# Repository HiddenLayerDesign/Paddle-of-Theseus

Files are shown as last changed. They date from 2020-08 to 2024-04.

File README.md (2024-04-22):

# Paddle-of-Theseus
This Repository holds the design work for Hidden Layer Design's "Paddle of Theseus" project.

Please take a look at [the Wiki](https://github.com/ChaseStewart/Paddle-of-Theseus/wiki) for in-depth information.

## Author
[Chase E Stewart](https://chasestewart.co) for [Hidden Layer Design](https://hiddenlayerdesign.com)

## Repository Contents
* **/Software/PadleFirmware** - Software Arduino project to program the Teensy 4.0. This Teensy is the main microcontroller for this project, and uses input sensor data to output MIDI commands to an external controller.
* **/Software/ClientApp** - Software [FBS](https://build-system.fman.io/)-based [PyQt](https://riverbankcomputing.com/software/pyqt/) project that builds a GUI application to allow users to configure the Paddle's saved settings in EEPROM.
* **/Software/StubPaddle** - Software Python program for ClientApp development to simulate a USB connection to the paddle. Requires a virtual COM port program on Windows to run.
* **/Hardware/Fritzing**   - DEPRECATED Fritzing file for project Hardware _NOTE: HW Diagram uses a Teensy3.1 but I have verified proper function on Teensy4.0 and TeensyLC_
* **/Hardware/Diagrams**   - DEPRECATED HW diagrams generated from the Fritzing file; currently these include a schematic, PCB image, and breadboard diagram
* **/Hardware/Components** - This contains the bill-of-materials for the relevant *electronics only* for this product. 

## Features
This project will create a bass-guitar-like skeumorphic MIDI instrument out of a standard rowing paddle (or arbitrary instrument body) and sensors. The Teensy microcontroller will take in sensor values and provide MIDI output to an external Audio DAW (In our case, we use Ableton Live and sometimes https://midi.city).

## Implementation Requirements
Implementing this project will require some knowledge of electronics, prototyping, and physical fabrication.

### Software Requirements
- [Arduino IDE](https://www.arduino.cc/en/Main/Software)
- [Arduino Teensyduino add-on](https://www.pjrc.com/teensy/td_download.html)
- [Arduino Teensy Loader](https://www.pjrc.com/teensy/loader.html)

### Hardware
The following is required to build this project.
- 1x [Teensy 4.0](https://www.pjrc.com/teensy-4-0/)
- 1x USB Micro cable
- 1x [Ultrasonic Rangefinder](https://www.adafruit.com/product/4019) or equivalent
- 1x [SparkFun Triple Axis Accelerometer Breakout](https://www.sparkfun.com/products/12756) or equivalent
- 1x [RGB Common-Anode Illuminated Rotary Encoder](https://www.sparkfun.com/products/15141)
- 1x [Clear Plastic Rotary Encoder Knob](https://www.sparkfun.com/products/10597)
- 1x [Illuminated Rotary Encoder Breakout Board](https://www.sparkfun.com/products/11722)
- 1x [USB Panel Mount Extension Cable](https://www.adafruit.com/product/3258)
- 1x [Custom CoreModule PCB](#)
- 1x [Custom FretBoard PCB](#)
- 1x [Custom StrumBoard PCB](#)
- Audio Software that supports MIDI (I use Ableton Live 8)

### Assembly
Assemble the Sensors and Teensy according to the schematic and breadboard diagrams in */Hardware/Diagrams*, paying special attention to the labeled inputs.

## Getting Started
- Download All Software Requirements above
  - Install Arduino IDE
  - Install Teensy Loader
  - Install Teensyduino SW libraries
- Clone this Repository
- Open `/Software/Main/main.ino` in Arduino 
- Configure Arduino Settings
  - Set `Tools>Board="Teensy 4.0"` to match the board you are using
  - Set `Tools>USB Type="Serial + MIDI"`
- Compile this project with `"Verify"`, then Flash with `Upload`
  - If needed, press the physical button on the Teensy to enable the bootloader. Ensure Serial connections are closed before hitting `Upload`

## Links
- Personal Website: https://chasestewart.co/
- Hidden Layer Design Website: https://HiddenLayerDesign.com
- Repository: https://github.com/ChaseStewart/Paddle-of-Theseus/

## License
<br />This work is licensed under a <a rel="license" href="http://creativecommons.org/licenses/by-sa/4.0/">Creative Commons Attribution-ShareAlike 4.0 International License</a>.

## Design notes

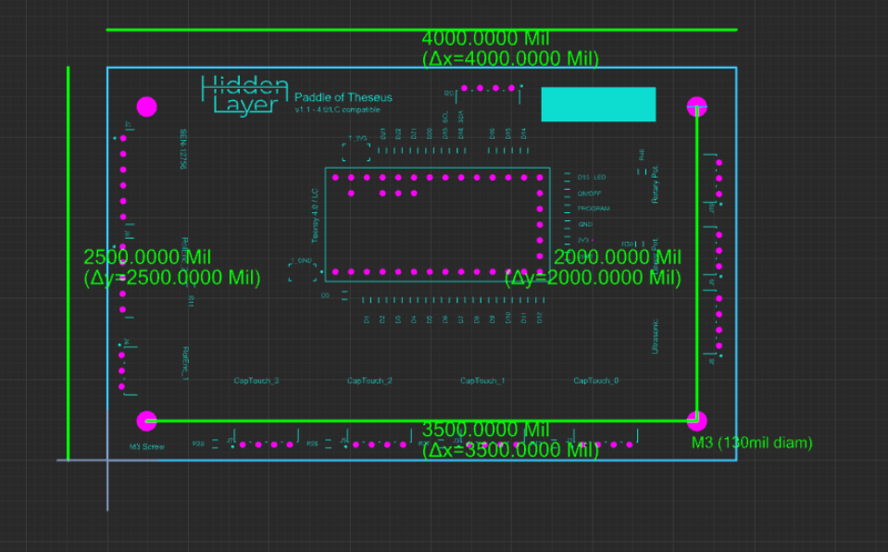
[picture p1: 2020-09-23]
Hardware/Diagrams/PCB Dimensions.PNG

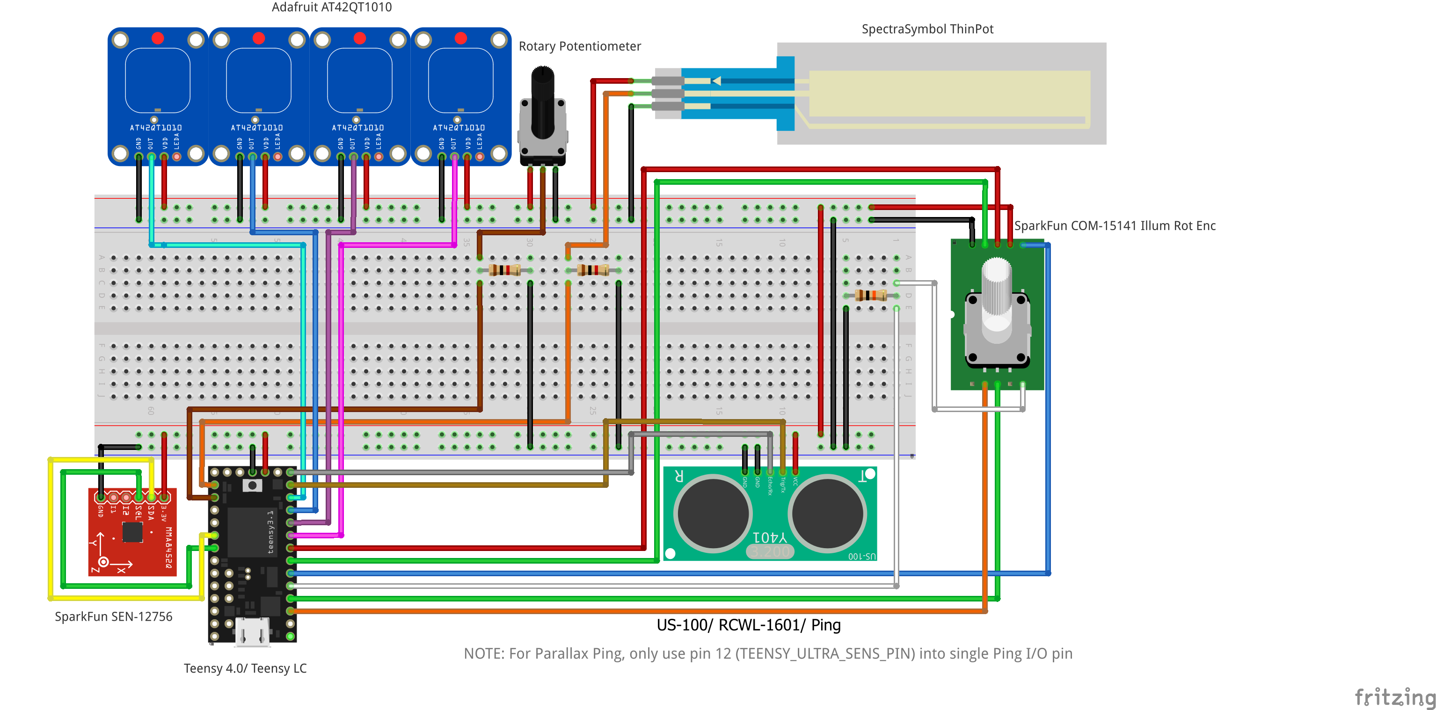
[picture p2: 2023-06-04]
Hardware/Diagrams/Paddle_of_Theseus_bb.png

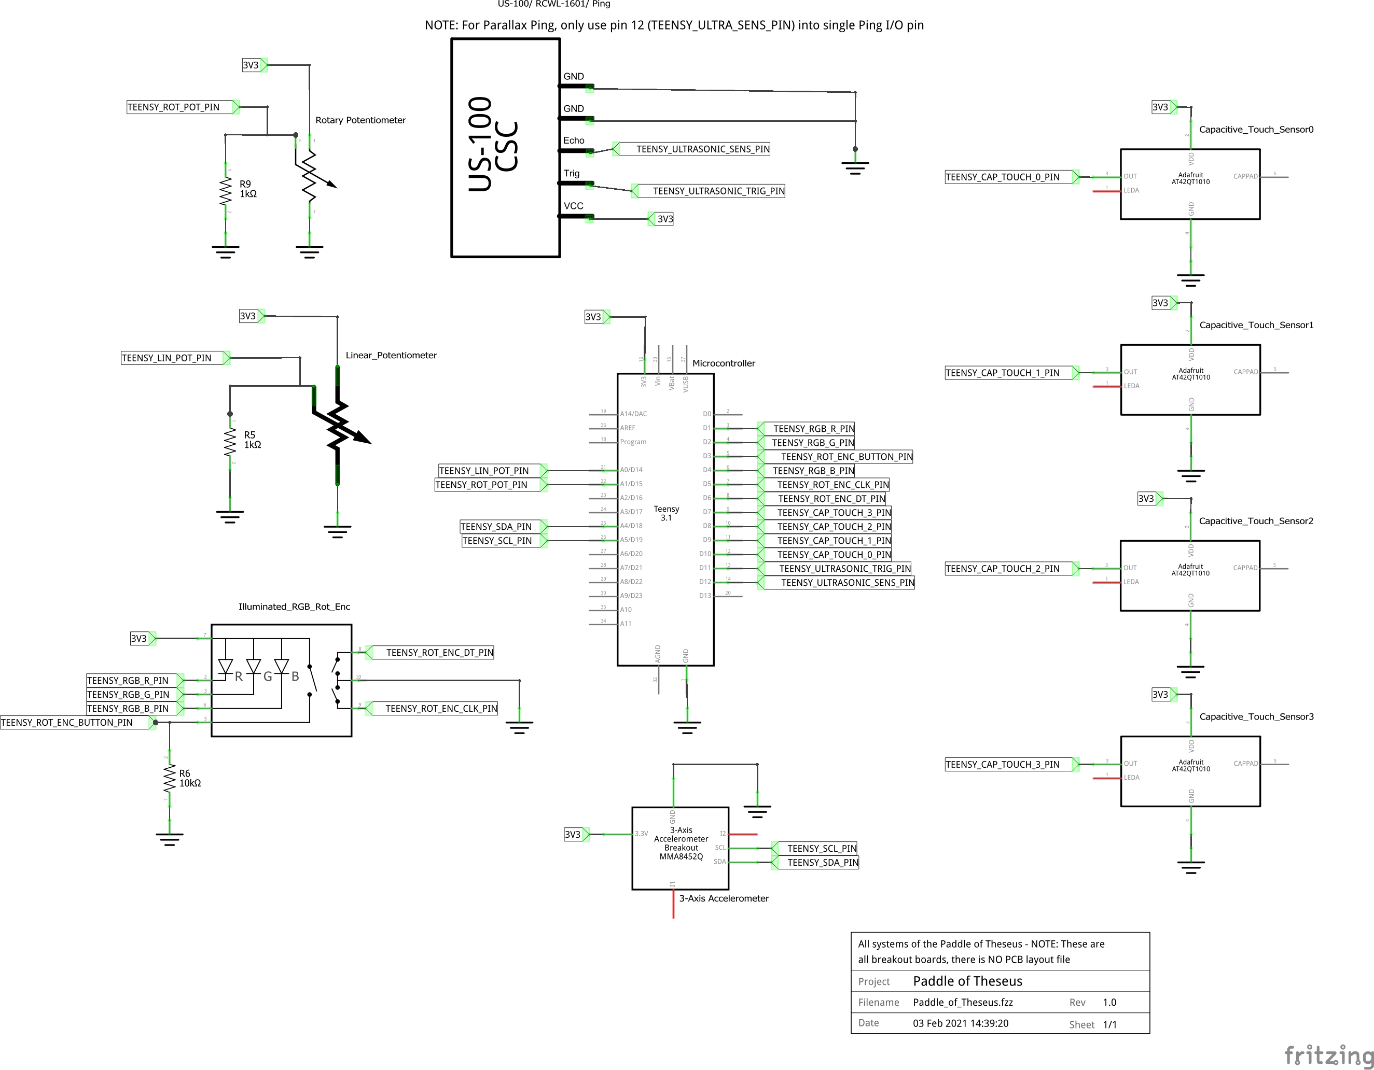
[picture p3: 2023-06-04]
Hardware/Diagrams/Paddle_of_Theseus_schem.png

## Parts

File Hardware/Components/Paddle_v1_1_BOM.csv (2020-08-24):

Manufacturer Part Number | Manufacturer | Digi-Key Part Number | Customer Reference | Quantity | Unit Price | Extended Price
PPTC051LFBN-RC | Sullins Connector Solutions | S6103-ND | Teensy Female Header Short | 1 | 0.47 | $0.47
PPTC141LFBN-RC | Sullins Connector Solutions | S7012-ND | Teensy Female Header Long | 2 | 0.91 | $1.82
640457-3 | TE Connectivity AMP Connectors | A19480-ND | Female Socket 3 | 3 | 0.19 | $0.57
640457-4 | TE Connectivity AMP Connectors | A1927-ND | Female Socket 4 | 6 | 0.25 | $1.50
640457-6 | TE Connectivity AMP Connectors | A1928-ND | Female Socket 6 | 1 | 0.48 | $0.48
640457-5 | TE Connectivity AMP Connectors | A19481-ND | Female Socket 5 | 1 | 0.4 | $0.40
RMCF0805ZT0R00 | Stackpole Electronics Inc | RMCF0805ZT0R00CT-ND | 0805 SMT Jumper | 30 | 0.0132 | $0.39
RC0805FR-0710KL | Yageo | 311-10.0KCRCT-ND | 0805 SMT 10K Resistor | 10 | 0.039 | $0.39
1374 | Adafruit Industries LLC | 1528-1782-ND | CapTouch | 4 | 5.95 | $23.80
3258 | Adafruit Industries LLC | 1528-1786-ND | Panel Mount USB | 1 | 4.95 | $4.95
SEN-12756 | SparkFun Electronics | 1568-1028-ND | Accelerometer | 1 | 9.95 | $9.95
65801-003LF | Amphenol ICC (FCI) | 609-2159-ND | ThinPot to female Headers | 1 | 1 | $1.00
TSP-L-0750-203-3%-RH | Spectra Symbol | 905-1090-ND | ThinPot | 1 | 40.94 | $40.94
22288040 | Molex | WM50013-04-ND | Male R/A Headers 4 | 4 | 0.29 | $1.16
22288030 | Molex | WM50013-03-ND | Male R/A Headers 3 | 1 | 0.23 | $0.23
22288050 | Molex | WM50013-05-ND | Male R/A Headers 5 | 1 | 0.36 | $0.36
22288060 | Molex | WM50013-06-ND | Male R/A Headers 6 | 1 | 0.43 | $0.43
4007 | Adafruit Industries LLC | 1528-2832-ND | Ultrasonic Rangefinder | 1 | 3.95 | $3.95
DEV-13305 | SparkFun Electronics | 1568-1233-ND | Teensy-LC | 1 | 14.38 | $14.38
3-640440-3 | TE Connectivity AMP Connectors | A31081-ND | Male Socket 3 | 3 | 0.19 | $0.57
3-640440-4 | TE Connectivity AMP Connectors | A31082-ND | Male Socket 4 | 6 | 0.27 | $1.62
3-640440-5 | TE Connectivity AMP Connectors | A31083-ND | Male Socket 5 | 1 | 0.38 | $0.38
3-640440-6 | TE Connectivity AMP Connectors | A31084-ND | Male Socket 6 | 1 | 0.44 | $0.44

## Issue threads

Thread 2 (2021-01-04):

Update schematic and fritzing image to reflect new sensor choices

ChaseStewart, 2021-01-04:
Looking at the README, I realize that at least the current Fritzing image and schematic make reference to the even-at-the-time-outdated Sparkfun 6DOF IMU

This ticket is to update all values in the schematic, Fritzing diagram, and BOM if needed to ensure the proper sensors are reflected in the documentation.

Closed 2021-02-04.

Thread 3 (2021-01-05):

Left-Handed mode should also invert rotary encoder rotation

ChaseStewart, 2021-01-05:

Closed 2021-02-08.

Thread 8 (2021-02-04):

Config menu currently allows user to disable ALL configurations simultaneously

ChaseStewart, 2021-02-04:
Find an elegant solution for the issue wherein a user disables ALL configurations simultaneously, thus most likely soft-locking the paddle as it attempts to cycle through all possible configs to find one that is enabled. This will likely need to be addressed in firmware, such that the soft-lock is logically impossible.

Closed 2021-02-05.

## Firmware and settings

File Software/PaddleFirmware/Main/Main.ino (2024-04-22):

/******************************************************* 
 *  File: Main.ino
 *    
 *  Author: Chase E. Stewart
 *  For Hidden Layer Design
 *  
 *  Note: You must select "Serial + MIDI" from the "Tools > USB Type" menu
 *  http://www.pjrc.com/teensy/td_midi.html
 *  
 *  License: Attribution-ShareAlike 4.0 International (CC BY-SA 4.0)    
 *  
 *******************************************************/
#include <Encoder.h>
#include <NewPing.h>

#include "Arduino.h"
#include "BoardLayout.hpp"
#include "ConfigConsole.hpp"
#include "MIDIConstants.hpp"
#include "MMA8452Q.hpp"
#include "NonVolatile.hpp"
#include "Preferences.hpp"
#include "QTouchBoard.hpp"
#include "RotaryEncoder.hpp"
#include "StrumButton.hpp"
#include "Ultrasonic.hpp"
#include "Version.hpp"

/* Static Prototypes */
static int getVolume(bool is_lefty_flipped);
static bool PollForSerial(unsigned long flip_time, bool is_green_not_yellow);
static void configurePins(void);
static void pingCheck(void);

/* external Prototypes */
void softRestart(void);

#ifdef DEBUG
static void printLoopDebugInfo(void);
static void printBanner(void);
#endif /* DEBUG */

/* Sensor class variables */
NewPing ultrasonic(PIN_ULTRA_TRIG, PIN_ULTRA_SENS, PITCH_BEND_MAX_CM+1);
Encoder RotaryEncoder = Encoder(PIN_ROT_ENC_A, PIN_ROT_ENC_C);
QTouchBoard fretBoard = QTouchBoard(PIN_FRET_1070_INT, PIN_FRET_2120_INT);
QTouchBoard strumBoard = QTouchBoard(PIN_STRUM_1070_INT, PIN_STRUM_2120_INT);
StrumButton button0 = StrumButton(STRUM_BUTTON_0);
StrumButton button1 = StrumButton(STRUM_BUTTON_1);
StrumButton button2 = StrumButton(STRUM_BUTTON_2);
StrumButton button3 = StrumButton(STRUM_BUTTON_3);

MMA8452Q accel;
Commander cmd;

int myInt = 0;
float myFloat = 0.0;

/* Ultrasonic Pitch Bend variables */
unsigned long ping_time;
unsigned long range_in_us;
unsigned long range_in_cm;
int curr_bend_val = 1;
int prev_bend_val = 0;

/* Rotary Potentiometer variables */
int analog_volume = 0;
int prev_analog_volume = 0;

// QTouchBoard variables
uint8_t strumStatus0, strumStatus1, strumStatus2;
uint8_t keyStatus0, keyStatus1, keyStatus2;

/* MIDI variables */
int current_fret = 0;
uint8_t strum_keys = 0;

/* Rotary Encoder Variables */
int curr_enc_reading = 0;
int prev_enc_reading = 1;
int constrained_enc_reading = 0;
enum rot_enc_state encoder_state = (rot_enc_state) ((int)ROT_ENC_ENUM_SIZE - 1);
int curr_rot_button = HIGH;
int prev_rot_button = HIGH;

/* General variables */
unsigned long flip_time;
bool is_lefty_flipped = false;
bool is_config_mode = false;
bool is_green_not_yellow = false;
config_t running_config;

/*
 * Setup PinModes and Serial port, Init digital sensors 
 */
void setup() 
{
  configurePins();    
  CheckUpdateVersionNumber();

  Serial.begin(9600);

  if (true == (is_config_mode = IsConfigModeEnabled()))
  {
    RotEncConfigPattern();
    initializeCommander();
    
    while (!Serial)
    {
      if (PollForSerial(flip_time, is_green_not_yellow))
      {
        is_green_not_yellow = !is_green_not_yellow;
        flip_time = millis() + 500;
      }
    }        
    RotEncSetLED(LED_YELLOW);
    initializeConfig();
    version_t s_version = GetVersionFromEEPROM();

    Serial.print("*** Paddle of Theseus Configuration Mode, Version ");
    Serial.print(s_version.version_major);
    Serial.print(".");
    Serial.print(s_version.version_minor);
    Serial.print(".");
    Serial.print(s_version.version_bugfix);
    Serial.println(" ***");
    Serial.println("Usage: Type \"help\" and then `Enter` key to get help");
    Serial.println("For all commands that take values, type \"command=VALUE\" and then `Enter` key");
    cmd.printCommandPrompt(); 
  }
  else
  {
    RotEncStandardPattern();

#ifdef DEBUG
    flip_time = millis() + 500;
    is_green_not_yellow = true;

    while (!Serial)
    {
      if (PollForSerial(flip_time, is_green_not_yellow))
      {
        is_green_not_yellow = !is_green_not_yellow;
        flip_time = millis() + 500;
      }
    }

    if (CrashReport) 
    {
      Serial.print(CrashReport);
      delay(5000);
    }
    printBanner();
#endif /* DEBUG */

    int num_disabled_configs = 0;
    /* Select the next enabled configuration */
    encoder_state = (rot_enc_state) encoder_state;
    
    while (!running_config.is_enabled)
    {
      encoder_state = (rot_enc_state) ((encoder_state + 1) % ROT_ENC_ENUM_SIZE);
      num_disabled_configs += 1;

      if (num_disabled_configs == ROT_ENC_ENUM_SIZE)
      {
        encoder_state = ROT_ENC_BLUE;
        running_config = loadConfigFromEEPROM(encoder_state);
        running_config.is_enabled = true;
        saveConfigToEEPROM(running_config, encoder_state);
        break;
      }
    }

    Wire.begin();
    fretBoard.begin(Wire);
    Wire1.begin();
    strumBoard.begin(Wire1);
    
    running_config = loadConfigFromEEPROM(encoder_state);
    RotEncSetLED(rot_enc_led_color_array[encoder_state]);
  }
  accel.init();
  WriteConfigMode(false);
}


/*
 * Read all sensors, create and send MIDI messages as needed.
 */
void loop() 
{
  /**
   * If in config mode, only Commander runs
   */
  if (is_config_mode)
  {
    cmd.update();
  }
  else
  {
    /* Check Lefty Flip status */
    accel.accel_update();
    is_lefty_flipped = accel.is_lefty_flipped();
  
    /* Sample Rotary Encoder Pushbutton */
    curr_rot_button = digitalRead(PIN_ROT_ENC_SW);
    if (curr_rot_button == HIGH && prev_rot_button == LOW)  
    {
      /**
       * Reboot into config mode if config gesture entered
       */
      if ((strumBoard.ReturnStrumKey(strumStatus0, strumStatus1, strumStatus2) & 0x0F) == 0x0F)
      {
          DEBUG_PRINT("Setting Config Mode!");
          WriteConfigMode(true);
          RotEncConfigPattern();
          softRestart();  
      }

      /* Select the next enabled configuration */
      do
      {
        encoder_state = (rot_enc_state) ((encoder_state + 1) % ROT_ENC_ENUM_SIZE);
        running_config = loadConfigFromEEPROM(encoder_state);
      } while (!running_config.is_enabled);

      /* Set the LED color to the next enabled config */
      RotEncSetLED(rot_enc_led_color_array[encoder_state]);
    }
    prev_rot_button = curr_rot_button;
    
    /* Sample Rotary Encoder Twist Knob */
    constrained_enc_reading = ProcessRotEnc(RotaryEncoder.read(), is_lefty_flipped); 
    RotaryEncoder.write( (is_lefty_flipped) ? 
                       (-1 *constrained_enc_reading) : constrained_enc_reading);
       
    if (constrained_enc_reading != prev_enc_reading)
    {
      usbMIDI.sendControlChange(running_config.control_channel, constrained_enc_reading, MIDI_CHANNEL_2);
    }
    prev_enc_reading = constrained_enc_reading;
  
    /* Read Fretboard */ 
    if (true) // TODO fix this to read from GPIO Interrupt pins
    {    
      keyStatus0 = fretBoard.GetLeastSigMask();
      keyStatus1 = fretBoard.GetMiddleMask();
      keyStatus2 = fretBoard.GetMostSigMask();
      current_fret = fretBoard.ReturnFret(keyStatus0, keyStatus1, keyStatus2);
    }

    /* Read Strumboard */
    if (strumBoard.isValueUpdate())
    {
      strumStatus0 = strumBoard.GetLeastSigMask();
      strumStatus1 = strumBoard.GetMiddleMask();
      strumStatus2 = strumBoard.GetMostSigMask();
      strum_keys = strumBoard.ReturnStrumKey(strumStatus0, strumStatus1, strumStatus2);
    }
     
    /* Send note on debounced rising edge of TEENSY_CAP_TOUCH1_PIN */
    button0.Update(strum_keys & 0x01);
    button1.Update(strum_keys & 0x02);
    button2.Update(strum_keys & 0x04);
    button3.Update(strum_keys & 0x08);

    if (button0.ShouldSendNote()) 
      button0.SendNote(current_fret, analog_volume, is_lefty_flipped,running_config);
    if (button1.ShouldSendNote()) 
      button1.SendNote(current_fret, analog_volume, is_lefty_flipped,running_config);
    if (button2.ShouldSendNote())
      button2.SendNote(current_fret, analog_volume, is_lefty_flipped,running_config);
    if (button3.ShouldSendNote())
      button3.SendNote(current_fret, analog_volume, is_lefty_flipped,running_config);

    button0.CheckMIDINeedsUpdate();
    button1.CheckMIDINeedsUpdate();
    button2.CheckMIDINeedsUpdate();
    button3.CheckMIDINeedsUpdate();

    /* Get Ultrasonic Distance sensor reading */
    if (micros() >= ping_time)
    {
      /* NOTE: due to using newPing timer, this has to indirectly set range_in_us */
      ultrasonic.ping_timer(pingCheck);
      range_in_cm = range_in_us / US_ROUNDTRIP_CM;
      ping_time += ULTRASONIC_PING_PERIOD;
    }
  
    /* constrain range_in_cm, but sufficiently low values are treated as high ones */
    if (range_in_cm < PITCH_BEND_MIN_CM || range_in_cm > PITCH_BEND_MAX_CM)
    {
      range_in_cm = PITCH_BEND_MAX_CM;
    }
  
    /* Decide whether to update ultrasonic sensor */
    curr_bend_val = SCALED_PITCH_BEND(range_in_cm);
    if (curr_bend_val!= prev_bend_val && abs(curr_bend_val- prev_bend_val) < MAX_PITCH_BEND_DELTA)
    {
      if (running_config.pitchbend_channel == MIDI_CTRL_CHG_PITCHBEND)
      {
        usbMIDI.sendPitchBend(curr_bend_val, MIDI_CHANNEL_2);
      }
      else if (running_config.pitchbend_channel < MIDI_CTRL_CHG_MAX)
      {        
        usbMIDI.sendControlChange(running_config.pitchbend_channel, ONEBYTE_SCALED_PITCH_BEND(range_in_cm), MIDI_CHANNEL_2);
      }
      else if (running_config.pitchbend_channel == MIDI_CTRL_CHG_INVAL)
      {
        // don't send pitchbend            
      }
      else // any invalid Control Change input value should be ignored
      {
        // also don't send pitchbend                    
      }
      prev_bend_val = curr_bend_val;
    }
  
    /* set volume */
    analog_volume = getVolume(is_lefty_flipped);
    constrain(analog_volume, 0, 127);
    if (analog_volume < TEENSY_MIN_VOLUME)
    {
      analog_volume = 0;
      if (prev_analog_volume >= TEENSY_MIN_VOLUME)
      {
        usbMIDI.sendNoteOff(button0.GetCurrentNote(), 0, MIDI_CHANNEL_2);
        usbMIDI.sendNoteOff(button1.GetCurrentNote(), 0, MIDI_CHANNEL_2);
        usbMIDI.sendNoteOff(button2.GetCurrentNote(), 0, MIDI_CHANNEL_2);
        usbMIDI.sendNoteOff(button3.GetCurrentNote(), 0, MIDI_CHANNEL_2);
      }
    }
    else
    {
      if (abs(prev_analog_volume - analog_volume) > 1)
      {
        usbMIDI.sendAfterTouch(analog_volume, MIDI_CHANNEL_2);
      }
    }
    prev_analog_volume = analog_volume;
    usbMIDI.send_now();
  
    /** 
     *  ignore incoming MIDI messages;
     *  
     *  MIDI Controllers should discard incoming MIDI messages.
     *  http://forum.pjrc.com/threads/24179-Teensy-3-Ableton-Analog-CC-causes-midi-crash
     */ 
    while (usbMIDI.read()); 
    
#ifdef DEBUG
    printLoopDebugInfo();
#endif  /* DEBUG */
  }
}

/**
 * Callback function to check whether ultrasonic sonar has returned data
 */
static void pingCheck(void)
{
  range_in_us = (ultrasonic.check_timer()) ? ultrasonic.ping_result : range_in_us +2;
}

/**
 * Do static configuration of pins as INPUT or OUTPUT
 */
static void configurePins(void)
{
  /* Set input sensor pins */
  pinMode(PIN_FRET_1070_INT, INPUT);
  pinMode(PIN_FRET_2120_INT, INPUT);
  pinMode(PIN_STRUM_1070_INT, INPUT);
  pinMode(PIN_STRUM_2120_INT, INPUT);
  pinMode(PIN_ROT_ENC_SW, INPUT);
  pinMode(PIN_ROT_POT, INPUT);

  /* The rotary switch LEDS are common anode with external pulldown */
  pinMode(PIN_ROT_LEDB, OUTPUT);
  pinMode(PIN_ROT_LEDG, OUTPUT);
  pinMode(PIN_ROT_LEDR, OUTPUT);  

  pinMode(PIN_TEENSY_LED, OUTPUT);
}

/**
 * Return the instrument volume, taking into account whether a left- or right-handed person is using the paddle
 * 
 * @param is_lefty_flipped [in] True == the paddle is currently lefty-flipped, else False
 * @return int Volume between 0-127 where 127 is MAX volume
 */
int getVolume(bool is_lefty_flipped)
{
  return (is_lefty_flipped) ?
            floor(analogRead(PIN_ROT_POT) * 128.0/1024.0) :
            floor((1024 - analogRead(PIN_ROT_POT)) * 128.0/1024.0);
}

/**
 * Just print a serial banner- this is to de-clutter setup()
 */
void printBanner(void)
{
  version_t s_version = GetVersionFromEEPROM();
#ifndef DEBUG
  (void) s_version; // remove warning
#endif /* !DEBUG */

  DEBUG_PRINTLN();
  DEBUG_PRINTLN();
  DEBUG_PRINTLN("***********************************************");
  DEBUG_PRINTLN("*               Paddle of Theseus             *");
  DEBUG_PRINTLN("*                                             *");
  DEBUG_PRINTLN("* By Chase E. Stewart for Hidden Layer Design *");
  DEBUG_PRINTLN("***********************************************");
  DEBUG_PRINT("Version ");
  DEBUG_PRINT(s_version.version_major);
  DEBUG_PRINT(".");
  DEBUG_PRINT(s_version.version_minor);
  DEBUG_PRINT(".");
  DEBUG_PRINT(s_version.version_bugfix);
  DEBUG_PRINTLN();
  DEBUG_PRINT("Config Mode enabled: ");
  DEBUG_PRINT((IsConfigModeEnabled()) ? "True " : "False");
  DEBUG_PRINTLN();
  DEBUG_PRINTLN();
}

/**
 * Use Carriage return to print a constantly-updating variable(s) once-per-loop
 */
void printLoopDebugInfo()
{
  DEBUG_PRINT("\rVolume: ");
  DEBUG_PRINT(analog_volume);
  DEBUG_PRINT("     ");
}

/**
 * Reset the Teensy in software
 */
void softRestart(void) 
{
  Serial.end();  // clears the serial monitor  if used
  REG_SCB_AIRCR = VAL_SCB_AIRCR_RESET;  // write value for restart
}

/**
 * Non-blocking function to check whether it's time to flip the LED, return whether LED was flipped
 * just a way to unclutter setup()
 * 
 * @param flip_time [in] timestamp in msec after which to flip the LED
 * @param is_green_not_yellow [in] True == set LED to green, else False == yellow
 * @return bool True == LED was flipped on this call, False == nothing happened
 */
bool PollForSerial(unsigned long flip_time, bool is_green_not_yellow)
{
  if (millis() > flip_time)
  {      
    RotEncSetLED((is_green_not_yellow) ? LED_GREEN : LED_YELLOW);
    return true;
  }
  return false;
}

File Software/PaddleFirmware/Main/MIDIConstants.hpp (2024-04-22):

/******************************************************* 
 *  File: MIDIConstants.hpp
 *    
 *  Author: Chase E. Stewart
 *  For Hidden Layer Design
 *  
 *  This design is built off of Teensy MIDI example code 
 *     and Seeed studio code for the Ultrasonic Rangefinder
 *     
 *  License: Attribution-ShareAlike 4.0 International (CC BY-SA 4.0)    
 *  
 *******************************************************/
 
#ifndef __MIDI_CONST_HPP__
#define __MIDI_CONST_HPP__

/* MIDI Channel Constants */
const int MIDI_CHANNEL_1  = 0;
const int MIDI_CHANNEL_2  = 1;
const int MIDI_CHANNEL_3  = 2;
const int MIDI_CHANNEL_4  = 3;
const int MIDI_CHANNEL_5  = 4;
const int MIDI_CHANNEL_6  = 5;
const int MIDI_CHANNEL_7  = 6;
const int MIDI_CHANNEL_8  = 7;
const int MIDI_CHANNEL_9  = 8;
const int MIDI_CHANNEL_10 = 9;
const int MIDI_CHANNEL_11 = 10;
const int MIDI_CHANNEL_12 = 11;
const int MIDI_CHANNEL_13 = 12;
const int MIDI_CHANNEL_14 = 13;
const int MIDI_CHANNEL_15 = 14;
const int MIDI_CHANNEL_16 = 15;

/* Generally accepted MIDI Control Change messages */
const int MIDI_CTRL_CHG_MOD_WHEEL  = 0x01;
const int MIDI_CTRL_CHG_MOD_BREATH = 0x02;
const int MIDI_CTRL_CHG_PORTAMENTO = 0x05;
const int MIDI_CTRL_CHG_CHAN_VOL   = 0x07;
const int MIDI_CTRL_CHG_EXPRESSION = 0x0B;
const int MIDI_CTRL_CHG_EFFECT_1   = 0x0C;
const int MIDI_CTRL_CHG_EFFECT_2   = 0x0D;
const int MIDI_CTRL_CHG_LEGATO_FSW = 0x44;
const int MIDI_CTRL_CHG_PITCHBEND  = 0xE0;
const int MIDI_CTRL_CHG_MAX        = 0x7F;
const int MIDI_CTRL_CHG_INVAL      = 0xFF;

const int MIDI_OCTAVE_LEN  = 7;
const int MIDI_NUM_OCTAVES = 4;
const int MIDI_SCALE_LEN = 128;

const int ROOT_NOTE_C = 0;
const int ROOT_NOTE_CSHARP = 1;
const int ROOT_NOTE_D = 2;
const int ROOT_NOTE_DSHARP = 3;
const int ROOT_NOTE_E = 4;
const int ROOT_NOTE_F = 5;
const int ROOT_NOTE_FSHARP = 6;
const int ROOT_NOTE_G = 7;
const int ROOT_NOTE_GSHARP = 8;
const int ROOT_NOTE_A = 9;
const int ROOT_NOTE_ASHARP = 10;
const int ROOT_NOTE_B = 11;

/* Various MIDI Scales- thanks to http://lawriecape.co.uk/theblog/index.php/archives/881 for writing these out */

/* major = W W H W W W H */
const int MAJOR_DELTAS[MIDI_SCALE_LEN] = {0, 2, 4, 5, 7, 9, 11, 12, 14, 16, 17, 19, 21, 23, 24, 26, 28, 29, 31, 33, 35, 36, 38, 40, 41, 43, 45, 47, 48, 
                                          50, 52, 53, 55, 57, 59, 60, 62, 64, 65, 67, 69, 71, 72, 74, 76, 77, 79, 81, 83, 84, 86, 88, 89, 91, 93, 95, 96,
                                          98, 100, 101, 103, 105, 107, 108, 110, 112, 113, 115, 117, 119, 120, 122, 124, 125, 127, 127, 127, 127, 127, 127, 
                                          127, 127, 127, 127, 127, 127, 127, 127, 127, 127, 127, 127, 127, 127, 127, 127, 127, 127, 127, 127, 127, 127, 127,
                                          127, 127, 127, 127, 127, 127, 127, 127, 127, 127, 127, 127, 127, 127, 127, 127, 127, 127, 127, 127, 127, 127, 127, 127, 127};
                                          
/* minor = W H W W H W W */
const int MINOR_DELTAS[MIDI_SCALE_LEN] = {0, 2, 3, 5, 7, 8, 10, 12, 14, 15, 17, 19, 20, 22, 24, 26, 27, 29, 31, 32, 34, 36, 38, 39, 41, 43, 44, 46, 48,
                                          50, 51, 53, 55, 56, 58, 60, 62, 63, 65, 67, 68, 70, 72, 74, 75, 77, 79, 80, 82, 84, 86, 87, 89, 91, 92, 94, 96, 
                                          98, 99, 101, 103, 104, 106, 108, 110, 111, 113, 115, 116, 118, 120, 122, 123, 125, 127, 127, 127, 127, 127, 127,
                                          127, 127, 127, 127, 127, 127, 127, 127, 127, 127, 127, 127, 127, 127, 127, 127, 127, 127, 127, 127, 127, 127, 127,
                                          127, 127, 127, 127, 127, 127, 127, 127, 127, 127, 127, 127, 127, 127, 127, 127, 127, 127, 127, 127, 127, 127, 127, 127, 127};

/* mixolydian = W W H W W H W */
const int MIXOLYDIAN_DELTAS[MIDI_SCALE_LEN] = {0, 2, 4, 5, 7, 9, 10, 12, 14, 16, 17, 19, 21, 22, 24, 26, 28, 29, 31, 33, 34, 36, 38, 40, 41, 43, 45, 46, 48,
                                               50, 52, 53, 55, 57, 58, 60, 62, 64, 65, 67, 69, 70, 72, 74, 76, 77, 79, 81, 82, 84, 86, 88, 89, 91, 93, 94, 96, 
                                               98, 100, 101, 103, 105, 106, 108, 110, 112, 113, 115, 117, 118, 120, 122, 124, 125, 127, 127, 127, 127, 127, 127,
                                               127, 127, 127, 127, 127, 127, 127, 127, 127, 127, 127, 127, 127, 127, 127, 127, 127, 127, 127, 127, 127, 127, 127,
                                               127, 127, 127, 127, 127, 127, 127, 127, 127, 127, 127, 127, 127, 127, 127, 127, 127, 127, 127, 127, 127, 127, 127, 127, 127};
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

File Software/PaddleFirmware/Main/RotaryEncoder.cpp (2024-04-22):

/******************************************************* 
 *  File: RotaryEncoder.cpp
 *    
 *  Author: Chase E. Stewart
 *  For Hidden Layer Design
 *  
 *  License: Attribution-ShareAlike 4.0 International (CC BY-SA 4.0)    
 *  
 *******************************************************/
 
#include "Arduino.h"
#include "RotaryEncoder.hpp"
#include "BoardLayout.hpp"
#include "Preferences.hpp"


void RotEncSetLED(uint8_t color)
{
  digitalWrite(PIN_ROT_LEDR, color & 0x1);
  digitalWrite(PIN_ROT_LEDG, color & 0x2);
  digitalWrite(PIN_ROT_LEDB, color & 0x4);
}

void RotEncStandardPattern(void)
{
  RotEncSetLED(LED_BLUE);
  delay(120);  
  RotEncSetLED(LED_PURPLE);
  delay(120);  
  RotEncSetLED(LED_GREEN);
  delay(120);  
  RotEncSetLED(LED_CYAN);
  delay(120);  
  RotEncSetLED(LED_RED);
  delay(120);  
  RotEncSetLED(LED_YELLOW);
  delay(120);  
  RotEncSetLED(LED_WHITE);
  delay(2000);  
}

void RotEncConfigPattern(void)
{
  for (int i=0; i < LED_PATTERN_NUM_REPEATS; i++)
  {
    RotEncSetLED(LED_GREEN);
    delay(250);  
    RotEncSetLED(LED_YELLOW);
    delay(250);  
  }
  RotEncSetLED(LED_OFF);
  delay(2000);  
}

void RotEncErrorPattern(void)
{
  for (int i=0; i < LED_PATTERN_NUM_REPEATS; i++)
  {
    RotEncSetLED(LED_RED);
    delay(250);  
    RotEncSetLED(LED_WHITE);
    delay(250);  
  }
  RotEncSetLED(LED_OFF);
  delay(2000);  
}

int32_t ProcessRotEnc(int32_t rotEncReading, bool isLeftyFlipped)
{
  int32_t rotEnc = (isLeftyFlipped) ? (-1 * rotEncReading) : rotEncReading ;
  return constrain(rotEnc, ROT_ENC_MIN, ROT_ENC_MAX);
}

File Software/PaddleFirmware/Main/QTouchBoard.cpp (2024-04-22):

/*!
 * @file QTouchBoard.cpp
 *
 * \brief Class to control pair of capacitive touch board for fretBoard and strumBoard
 * 
 * These two boards mimic the affordances of a guitar using special copper capacitive-touch
 * zones inscribed onto the PCBs and interpreted by AT42QT series QTouch sensors. Thus,
 * the StrumBoard and FretBoard are each a "QTouch Board". The boards even have the same
 * Bill of Materials between them, the only difference is size, count, and position of touch regions
 * 
 * Author: Chase E. Stewart for Hidden Layer Design
 *
 */
#include "QTouchBoard.hpp"
#include "I2CHandler.hpp"
#include "BoardLayout.hpp"

/**************************************************************************/
/*!
    @brief    Creates QTouchBoard connected to one of the two I2c instances and sets up chips
    @param    *inStream
              Reference to one of the I2C TwoWire streams, Wire or Wire1
    @param    initChips
              True == Initialize the AT42QT2120 and AT42QT1070 over I2C, else False
*/
/**************************************************************************/
QTouchBoard::QTouchBoard(int int1070, int int2120)
{
  // set _i2cStream later in setup()
  this->_intPin1070 = int1070;
  this->_intPin2120 = int2120;
  pinMode(this->_intPin1070, INPUT);
  pinMode(this->_intPin2120, INPUT);

  this->QT1070Handler = I2CHandler();
  this->QT2120Handler = I2CHandler();
}

/**************************************************************************/
/*!
    @brief    Take in initialized TwoWire object and add it to the QTouchBoard
*/
/**************************************************************************/
void QTouchBoard::begin(TwoWire &inStream)
{
  this->QT1070Handler.begin(inStream, QTOUCH1070_ADDR);
  this->QT2120Handler.begin(inStream, QTOUCH2120_ADDR);
  initQTouch();
}

QTouchBoard::~QTouchBoard() { }

/**************************************************************************/
/*!
    @brief    Creates QTouchBoard and initializes pins
*/
/**************************************************************************/
void QTouchBoard::initQTouch()
{
    _InitQT1070();
    _InitQT2120();  
}

/**************************************************************************/
/*!
    @brief    Initialize the register settings for the AT42QT1070
*/
/**************************************************************************/
void QTouchBoard::_InitQT1070()
{
  // Get Chip ID
  uint8_t chipId = QT1070Handler.ReadSingleRegister(REG_QT1070_CHIP_ID);
  if (chipId != VAL_QT2120_CHIP_ID)
  {
    DEBUG_PRINT("QT1070 chipId = 0x"); DEBUG_PRINT_HEX(chipId); DEBUG_PRINT(", should be 0x"); DEBUG_PRINTLN_HEX(VAL_QT1070_CHIP_ID);
  }

  // Get FW version
  uint8_t versionByte = QT1070Handler.ReadSingleRegister(REG_QT1070_VERSION);
  uint8_t versionMajor = (versionByte & 0xF0) >> 4;
  uint8_t versionMinor = (versionByte & 0x0F);

#ifndef DEBUG
  (void) versionMajor;
  (void) versionMinor;
#endif

  DEBUG_PRINT("Firmware version = "); DEBUG_PRINT(versionMajor); DEBUG_PRINT("."); DEBUG_PRINTLN(versionMinor);

  // Set touch integration
  for (int i=0; i<7; i++)
  {
    QT1070Handler.WriteSingleRegister(i + REG_QT1070_INTEGRATION, 4); // TODO revisit these settings
    QT1070Handler.WriteSingleRegister(i + REG_QT1070_AVE_AKS, 0x20); // TODO revisit these settings
  }

  // Set Low Power Mode
  QT1070Handler.WriteSingleRegister(54, 1); // TODO revisit these settings
}

/**************************************************************************/
/*!
    @brief    Initialize the register settings for the AT42QT2120
*/
/**************************************************************************/
void QTouchBoard::_InitQT2120()
{
  // Get Chip ID
  uint8_t chipId = QT2120Handler.ReadSingleRegister(REG_QT2120_CHIP_ID);
  if (chipId != VAL_QT2120_CHIP_ID)
  {
    DEBUG_PRINT("QT2120 chipId = 0x"); DEBUG_PRINT_HEX(chipId); DEBUG_PRINT(", should be 0x"); DEBUG_PRINTLN_HEX(VAL_QT2120_CHIP_ID);
  }

  // Get FW version
  uint8_t versionByte = QT2120Handler.ReadSingleRegister(REG_QT2120_VERSION);
  uint8_t versionMajor = (versionByte & 0xF0) >> 4;
  uint8_t versionMinor = (versionByte & 0x0F);

#ifndef DEBUG
  (void) versionMajor;
  (void) versionMinor;
#endif

  DEBUG_PRINT("Firmware version = "); DEBUG_PRINT(versionMajor); DEBUG_PRINT("."); DEBUG_PRINTLN(versionMinor);

  // Set touch integration
  QT2120Handler.WriteSingleRegister(11, 4); // TODO revisit these settings

  // Set drift hold time
  QT2120Handler.WriteSingleRegister(13, 3); // TODO revisit these settings

  // Set detect threshold
  for (int i=0; i<12; i++)
  {
      QT2120Handler.WriteSingleRegister(16+i, 19); // TODO revisit these settings
  } 
}
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

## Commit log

2020-03-08 Initial Arduino SW commit, Ultrasonic+MIDI working
    This is the initial commit of working software+ README for this project. With this commit:
    * MIDI controller is properly initialized, and is starting a new random note from a MIDI-encoded blues scale every 2 seconds
    * Additionally, the Ultrasonic Rangefinder is capturing distance in centimeters every 50 msec, and using this value to actuate MIDI pitch bend
    TODO:
    * Initial communication with 6DoF IMU, get WHOAMI from ITG3200 and ADXL345
    * Build out 6DoF IMU drivers
    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
2020-03-14 Support Linear Pot, starting header for ADXL345
    Just a quick commit because the linear potentiometer is integrated into the demo..
    Still TODO:
    * Initial communication/integration with the ADXL345 and the ITG3200
    * Standard guitar rotary potentiometer
    * Integrate AT42QT1010
    Known Issues:
    * Linear Potentiometer has a nonlinear sensitivity curve
    * Currently mapping notes to a crude scale
    * Notes automatically firing every 200 msec
    [Main.ino]
2020-03-18 Beginning to integrate ADXL345
    Now communicating with the accelerometer, whole circuit is now wired, but still need to test the rotary potentiometer, momentary capacitive touch sensor, and perhaps the rotary potentiometer's moment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
    Still TODO
    * Rest of the ADXL345 integration and get valuable output to tie to MIDI commands
    * Tie cap touch GPIO to MIDI note formation
    * Speed up pitch-bend resolution
    * Get any response from ITG3200
    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
2020-03-21 Improve responsivity, Capacitive touch working nicely
    Turns out that the `delayMicroseconds()` function does not play nicely on Teensy4.0, changing the delay function to just `delay()` appears to work well with the Ultrasonic Sensor.
    With this, the foundation of the Paddle_of_Theseus is pretty solid; the operations of "fret", "strum", and "whammy" work reliably and create good sounds on Ableton.
    * Get the Rotary Potentiometer for static wet/dry effects or something
    * Now purchase several Cap Touch sensors and use them for chords
    * Document HW connections via Fritzing, Eagle, or something
    * Integrate Accelerometer to modify the sound
    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
2020-03-23 Add Diagram PNG files, MIDI Ctrl_Chg Messages
    Add the Fritzing document for circuit hook-up, as well as a schematic and "breadboard image" detailing how the sensors go together. Finally, add some new messages to MIDI constants, at least one of which should shortly be used by the ADXL345
    [Paddle_of_Theseus.fzz]
2020-03-23 Improve clarity of Fritzing Diagrams, add basic .gitignore
    The Fritzing diagrams are approaching maximum clarity, so time to put an image into the README.md.
    [Paddle_of_Theseus.fzz]
2020-04-06 MIDI settings via Rotary Encoder now supported
    I've got the rotary encoder working now- push in the button to change which MIDI setting you want to change, and then twist the knob to change the value. Acceptable values are 0-255, and each knob re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
    **NOTE** Now pitch-bend only sends MIDI messages while the twist-knob is not changing, and accelerometer now only changes if the Rotary push-button is set to ROT_ENC_OFF (aka state 0, when no MIDI se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
2020-04-08 Updated rot_enc schematic + Fritzing Diagram
    Realized that what I have working here on my desk does not match what I was advertising in the fritzing diagram + schematic. I updated this to match the reference that I used to get the rotary encode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
    [Paddle_of_Theseus.fzz]
2020-04-15 Main loop not perfect but much more fun!
    Moving the ultrasonic function to only run during a single rotary encoder state has made the paddle much more fun to play- so I'll find a way to improve what I have now but also keep it in spirit. I 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
2020-04-23 Add HYPER mode, beta release for BEAT 4/24 meeting
    Not that I'm keeping a version # but this is the release I'll be using to demo on Friday.
    Quick summary of changes:
    1. Fixed sluggishness of cap touch while Ultrasonic sensor is running
    2. Re-introduced Ultrasonic sensor in all rotary-encoder states now that it is working properly. I probably need to add an optional disable-Ultrasonic mode now, but not for this demo!
    3. Removed rising edge detect bug wherein holding down the cap-touch sensor would result in a constant stream of notes every DEBOUNCE_PERIOD msec()
    4. Re-added point 3. as an optional "hyper mode" Encoder state, which is knowable because the MCU LED is off, and now the space be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
    [Main.ino]
2020-04-30 Replace generic Bourns Rotary_Encoder with SparkFun RGB Rotary_Encoder, add color code
    This change now allows for a twistable and pushable rotary encoder that gracefully displays its state via the knob itself changing color. This required the following:
    * Change to the hardware and resulting Fritzing diagrams
    * modifications to the SW to make use of the new RGB illumination *AND* change the switch to trigger on falling edge rather than rising edge
    * Change to the README detailing the new purchases
    [Paddle_of_Theseus.fzz]
2020-05-01 Crappy code has 3 cap-touch sensors working simultaneously, MAJOR MILESTONE!!
    Now 3 cap touch sensors are simultaneously supported, respectively doing the root, 3rd note up in the scale, and 5th note up in the scale. More details when the awful code here gets cleaned up.
2020-05-04 Rotary Encoder Master Volume support
    Again just a quick hack to put master volume into one of the rotary encoder settings. This one is indicated when the RGB LED is completely off on the Rotary Encoder. I still want to fully clean up th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
2020-07-30 Clean up and modularize PaddleOfTheseus code
    Moved out sensor functions into sensor-based files, simplified some bloated logic- everything works as before.
2020-07-31 Further minor optimizations, reduce ultrasonic range to 30cm
    I really should test these changes- don't trust this commit on faith
2020-07-31 Move CapTouch into class, lower pitch bend sensitivity
    The code is much easier to read, doesn't repeat nearly as much, and pitch bend sounds better with less sensitivity.
    [Main.ino]
2020-08-20 First Flawed PCB completed
    The Paddle of Theseus PCB has been assembled and tested, and there are a few takeaways:
    * The SW now supports 4 capTouch sensors rather than 3
    * Moved LinearPotentiometer pin from magic # to the TeensyBSP
    * Rearranged TeensyBSP pins to match current state of PCB
    However, there are still some flaws to be addressed with the PCB itself:
    * Mis-wired the Rotary Encoder's 5-pin side
    * Wired Linear Potentiometer to the on/off pin (was going off a Teensy 3.2 pinout guide)- pins need to be shifted to make room for Linear Potentiometer
    * Linear Potentiometer GND/VCC pins may be flipped
    [Main.ino]
2020-08-24 Create Paddle_v1_1_BOM.csv
    after applying cost cutting, total low-volume BOM cost is $110 + PCB (~$2) + physical body per instrument
    [Paddle_v1_1_BOM.csv]
2020-09-08 Make Ultrasonic work for Parallax or US100, option to invert rotary potentiometer
    [Main.ino]
2020-09-22 V1.1 PCBs working for LC/4.0, update ultrasonic, replace Accel
    Updates:
    * US-100 sensors are working instead of Parallax Ping sensors
    * Replaced the ADXL345/ITG3200 sensor modules with the sparkfun SEN_12756
    * 2 of 3 PCBs are working 100%, a 3rd will be ready soon
    * Better build out the Accelerometer
    * Add quality of life and feel improvements to core loop
    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
    [MMA8452Q.cpp, Main.ino]
2020-09-23 Switch to #define DEBUG-based compile-time printing
    Added a #define that determines whether the paddle will open a serial connection and print at all.
2020-12-28 Ultrasonic sensor performance improvement, accelerometer "lefty mode", simplification of CapTouch logic
    Lots of good stuff here, generally improving on the foundation previously laid before getting the instrument body
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2020-12-29 Lefty Flip now properly inverts cap touch keys as well as volume, unlocked MIDI from ionian scale, simplified main-loop for send note
    [MIDIConstants.h, Main.ino]
2020-12-30 Update README.md
    * Updated model of 6-axis accelerometer, removed warnings about the old deprecated 6DOF IMU
    * Swapped out reference to hiddenlayer email
    * Removed TODO bullet in `Repository Contents`
    * Added references throughout to Teensy LC as a viable board for this project
2020-12-30 EEPROM, improve capTouch class, ColorPatterns, replace controlChanges with scales
    * Added version.h
    * Added EEPROM read/writes for config/config_mode/version
    * Added physical trigger to enter config mode
    * Added SW reset, set EEPROM flag when physical trigger is set
    * Added RotaryEncoder patterns to display on boot and show the state
    * Added "Preferences.h" for all empirical "tuning" variables
    * Greatly simplified logic in main.ino and reduced number of variables
    [MMA8452Q.cpp, Main.ino, NonVolatile.h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]
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2021-01-21 Commit partial changes to transfer to desktop computer
    It's not all working, but I need to commit these to keep going.
    Client app partially done, can now read out status and can almost change status on paddle via callbacks but still hitting errors.
    [Main.ino]
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2021-02-04 Update Fritzing Document along with Schematic and Breadboard diagram
    Updated to reflect the real sensors used, and generally cleaned up a bit.
    [Paddle_of_Theseus.fzz]
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2021-02-04 Update DocumentFrame to reflect updated schematic version/date
    Should have got this the first time, whoops- that's what I get for no reviewers.
    [Paddle_of_Theseus.fzz]
2021-02-05 Force enable ROT_ENC_BLUE if no configs are enabled on boot.
    Fix potential softlock issue by forcing the blue config to enabled if all configs are disabled via the config tool or CLI. This also updates the EEPROM, so re-opening the tool or CLI after disabling all configs will reflect BLUE being enabled- so the state is properly maintained across sessions and is accurate from performance to stored data.
    [Paddle_of_Theseus.fzz]
2021-02-08 Fix NoteScale, add chromatic scale, fix root_note assignment in PoTConfig, GUI properly loads state for dropdowns
    enough said- closes several tickets
    [MIDIConstants.h, NonVolatile.h]
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2021-02-25 Fix logic for when all configs are disabled
    The last attempt at this was incorrect- this one simultaneously
    * prevents having a no-enabled-configs situation, while also
    * keeps previous config settings intact
    [Main.ino]
2021-03-07 Fix EEPROM location collisions
    This was clearly a bug; locations {100,125,126,127} collided with the color_config regions and should never have been used after the color_config memory map was developed. Oh well, fixed now!
    [NonVolatile.h]
2021-03-07 BUGFIX: Fix volume scaling to fit MIDI scale
    whoops- just like note and pitch-bend scale, MIDI velocity is [0-127]. Oh well, caught now!
    [Main.ino]
2021-03-08 BUGFIX: Fixed bug in configCLI code
    When we were changing the color of the config, we were not also loading the config- this resulted in a sort of "stamping effect" when changing between colors that had different configs. This should be the last issue with EEPROM saved settings.
    Also:
    * Bumped version to 1.0.0 !!!
    * Fixed syntax issue with PollForSerial when #debug was defined
    * Removed OBE saveColorHandler callback command (every setting effectively does this now).
    [Main.ino, NonVolatile.h]
2021-04-15 Implement Multi-Octave configuration
    Resolves #9
    Both the client PoTConfig tool and the firmware are aware of a new "octave" config var distinct from "root_note" that will allow users more control over their instrument config.
    [MIDIConstants.h, NonVolatile.h]
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2022-10-05 Force full reload after set_gui_config_from_serial
    This fixes an issue wherein the PitchBend sub-menu would stay collapsed after doing a resetDefaults to re-enable pitch bend.
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2022-10-17 BUGFIX fix initial state, use configureTab more
    Had an issue where Pitchbend Enable UI representation was not ironclad, due to a slight difference in flow depending on whether the app was first loading or whether user was changing first tab. This appears to be fixed now
2024-04-09 WONT COMPILE: Rough file changes, move only. Will fix to work in subsequent commits
    [BoardLayout.hpp, MIDIConstants.hpp, NonVolatile.hpp]
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2024-04-09 BUGFIX uninitialized Wire*, MMA8452Q wrong Wire
    * Add improvement of printing Crash file to serial if there was a crash
    * Fix two bugs to have the Paddle firmware running stably
    - MMA8452Q was trying to use Wire while it was hooked up to Wire1
    - Both QTouchBoards were trying to use Wire* uninitialized, added initialization
    With this the paddle is still not initializing notes properly, but it is running stably, and the QTouchBoards are doing their part.
    [MMA8452Q.cpp, Main.ino]
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2024-04-10 Swap unconditional prints to DEBUG_PRINT
    [QTouchBoard.cpp]
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2024-04-10 Tighten StrumButton class and More Cleanup
    * Move StrumBoard class vars to private and provide getters to close gaps
    * More and better comments in places
    * Changed boot LED pattern speed
    * Made use of EEPROM.update to shorten some code, and generally replace EEPROM.write
    * Minor tightening of Main's setup() function
    * Get rid of references to trying to keep the door open to use Teensy LC
    [BoardLayout.hpp, Main.ino, NonVolatile.hpp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]
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2024-04-10 Update README.md re-remove reference to Teensy LC
    Whoops, too much CTRL+Z
